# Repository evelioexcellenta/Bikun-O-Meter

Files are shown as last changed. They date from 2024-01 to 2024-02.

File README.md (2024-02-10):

# Bikun-O-Meter

## Overview
Our project aims to develop a web-based, battery-powered system for monitoring and analyzing crowd density at bus stops. Using ESP32CAM to capture images, the data is sent to a server to measure parameters such as headcount and stop area density. This system uses a TensorFlow lite framework and Real-time results are displayed on the website. 

## Concept
This system is divided into three parts: Electrical and Mechanical hardware, Image Recognition processing, and a Website. The microprocessor used is an ESP-32CAM, which connects to a WiFi Modem capable of transmitting captured pictures to Firebase Storage. The pictures are then downloaded by a Raspberry Pi 3B server and processed using an Image Recognition Algorithm from the TensorFlow Lite framework to identify the number of people and buses at the bus stop. The processed data is then uploaded to a website in real-time via the Firebase Realtime Database. For the power source, this system used a 5V battery module consisting of 2 18650 batteries connected in series and the voltage supply passes through a step-down buck converter.

The system provides a user-friendly web interface for accessing real-time data and includes a feature for storing historical data to observe crowd trends over time. With innovative technology and battery energy, this adaptable system can be installed at various bus stop locations without relying on external power sources.

## Battery Calculation
This system is aimed to operate without being connected to external power sources for at least a week. Therefore, we can estimate the required power. The system is set to turn on for 10 seconds and then go into DeepSleep mode for 50 seconds. So, it will be on for approximately 1.833 hours per day. If we want it to run for 7 days, it will be on for a total of 12.833 hours. Assuming an ESP32-CAM consumes 260mA of power, the battery capacity needed to power the system for 7 days is 3336.667 mAh. We use two Sony VCT6 batteries with a capacity of 3500mAh each, connected in series. We chose batteries with a capacity of 3500mAh to provide backup power so that the system could last for a week without shutting down immediately. Additionally, the batteries are connected in series to obtain a voltage of 7.4V - 8.4V, which will then be reduced to 5V using a buck converter module to be connected to the ESP32CAM.

## Result
Based on the assembly and testing stages, the results show that the tool is capable of sending information about the situation and crowd levels at the Faculty Bus Stop. The graph indicates that the crowd situation at the stop increases at certain times, namely during class schedules. Additionally, a decrease in the graph indicates that the  bus is present to transport passengers.

download 1

 ## Visit our website at: 
 https://bikun-o-meter.netlify.app/

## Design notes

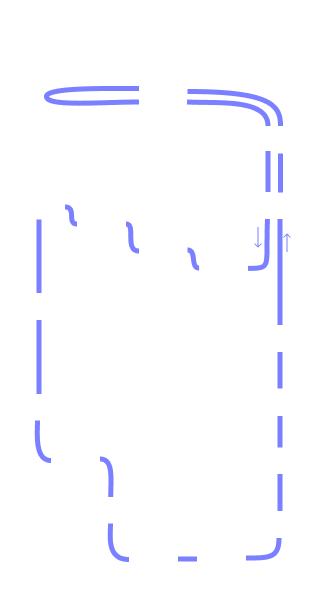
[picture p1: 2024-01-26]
Website/img/frame-7.png

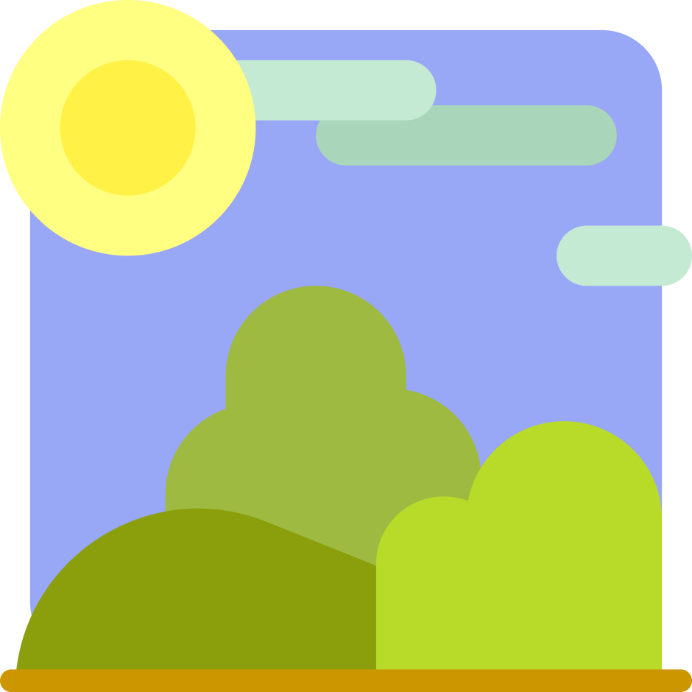
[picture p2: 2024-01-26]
Website/img/group-16.png

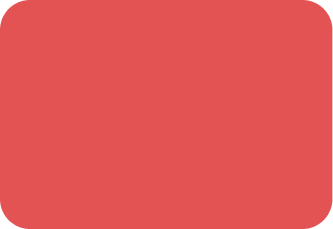
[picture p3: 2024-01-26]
Website/img/rectangle-16.png

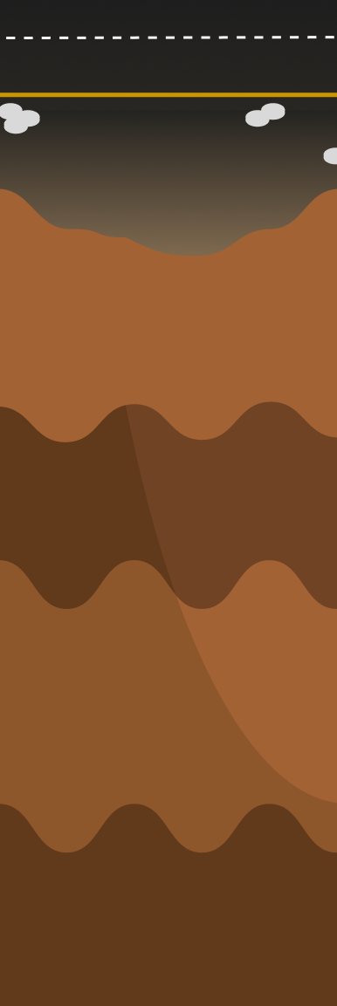
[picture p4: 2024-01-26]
Website/img/mask-group1.png

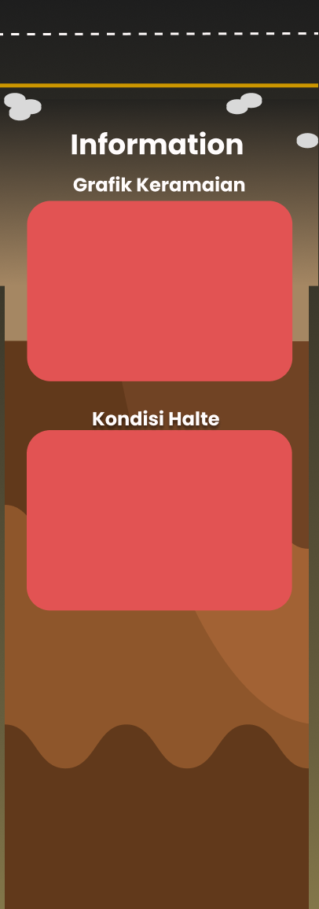
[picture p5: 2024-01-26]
Website/img/mask-group.png

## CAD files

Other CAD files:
Case/Casing Despro.iam
Case/Front.ipt
Case/fullback.ipt

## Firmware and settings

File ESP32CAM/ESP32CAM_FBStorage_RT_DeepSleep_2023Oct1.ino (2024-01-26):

#include "Arduino.h"
#include "WiFi.h"
#include "esp_camera.h"
#include "soc/soc.h"           // Disable brownout problems
#include "soc/rtc_cntl_reg.h"  // Disable brownout problems
#include "driver/rtc_io.h"
#include <LittleFS.h>
#include <FS.h>
#include <Firebase_ESP_Client.h>
//Provide the token generation process info.
#include <addons/TokenHelper.h>
#include "time.h"
//Provide the RTDB payload printing info and other helper functions.
#include "addons/RTDBHelper.h"
#define uS_TO_S_FACTOR 1000000ULL  /* Conversion factor for micro seconds to seconds */
#define TIME_TO_SLEEP  50        /* Time ESP32 will go to sleep (in seconds) */
int NightTime = 600; /*Time ESP will go to sleep 10 hours (10*60min)*/
//RTC_DATA_ATTR int bootCount = 0;
RTC_DATA_ATTR bool takeNewPhoto = true;

//Replace with your network credentials
const char* ssid = "wifi ssid";
const char* password = "wifi password";

const char* ntpServer = "pool.ntp.org";
const long  gmtOffset_sec = 7*3600;
const int   daylightOffset_sec = 0;

// Insert Firebase project API Key
#define API_KEY "input your API key"

// Insert Authorized Email and Corresponding Password
#define USER_EMAIL "input email"
#define USER_PASSWORD "input password"

// Insert Firebase storage bucket ID e.g bucket-name.appspot.com
#define STORAGE_BUCKET_ID "myhalte.appspot.com"
// Insert RTDB URLefine the RTDB URL
//#define DATABASE_URL ""

// Photo File Name to save in LittleFS
#define FILE_PHOTO_PATH "/photo.jpg"
#define BUCKET_PHOTO "/data/photo.jpg"

// OV2640 camera module pins (CAMERA_MODEL_AI_THINKER)
#define PWDN_GPIO_NUM     32
#define RESET_GPIO_NUM    -1
#define XCLK_GPIO_NUM      0
#define SIOD_GPIO_NUM     26
#define SIOC_GPIO_NUM     27
#define Y9_GPIO_NUM       35
#define Y8_GPIO_NUM       34
#define Y7_GPIO_NUM       39
#define Y6_GPIO_NUM       36
#define Y5_GPIO_NUM       21
#define Y4_GPIO_NUM       19
#define Y3_GPIO_NUM       18
#define Y2_GPIO_NUM        5
#define VSYNC_GPIO_NUM    25
#define HREF_GPIO_NUM     23
#define PCLK_GPIO_NUM     22

//boolean takeNewPhoto = true;

//Define Firebase Data objects
FirebaseData fbdo;
FirebaseAuth auth;
FirebaseConfig configF;
bool signupOK = false;

void fcsUploadCallback(FCS_UploadStatusInfo info);

bool taskCompleted = false;
int currentMinute;
int currentHour;

void printLocalTime()
{
  struct tm timeinfo;
 
  if(!getLocalTime(&timeinfo)){
    Serial.println("Failed to obtain time");
    return;
  }
  Serial.println(&timeinfo, "%A, %B %d %Y %H:%M:%S");
  currentMinute = timeinfo.tm_min;
  currentHour = timeinfo.tm_hour;
}


// Capture Photo and Save it to LittleFS
void capturePhotoSaveLittleFS( void ) {
  // Dispose first pictures because of bad quality
  camera_fb_t* fb = NULL;
  // Skip first 3 frames (increase/decrease number as needed).
  for (int i = 0; i < 4; i++) {
    fb = esp_camera_fb_get();
    esp_camera_fb_return(fb);
    fb = NULL;
  }
    
  // Take a new photo
  fb = NULL;  
  fb = esp_camera_fb_get();  
  if(!fb) {
    Serial.println("Camera capture failed");
    delay(1000);
    ESP.restart();
  }  

  // Photo file name
  Serial.printf("Picture file name: %s\n", FILE_PHOTO_PATH);
  File file = LittleFS.open(FILE_PHOTO_PATH, FILE_WRITE);

  // Insert the data in the photo file
  if (!file) {
    Serial.println("Failed to open file in writing mode");
  }
  else {
    file.write(fb->buf, fb->len); // payload (image), payload length
    Serial.print("The picture has been saved in ");
    Serial.print(FILE_PHOTO_PATH);
    Serial.print(" - Size: ");
    Serial.print(fb->len);
    Serial.println(" bytes");
  }
  // Close the file
  file.close();
  esp_camera_fb_return(fb);
}

void initWiFi(){
  WiFi.begin(ssid, password);
  while (WiFi.status() != WL_CONNECTED) {
    delay(1000);
    Serial.println("Connecting to WiFi...");
  }
}

void initLittleFS(){
  if (!LittleFS.begin(true)) {
    Serial.println("An Error has occurred while mounting LittleFS");
    ESP.restart();
  }
  else {
    delay(500);
    Serial.println("LittleFS mounted successfully");
  }
}

void initCamera(){
 // OV2640 camera module
  camera_config_t config;
  config.ledc_channel = LEDC_CHANNEL_0;
  config.ledc_timer = LEDC_TIMER_0;
  config.pin_d0 = Y2_GPIO_NUM;
  config.pin_d1 = Y3_GPIO_NUM;
  config.pin_d2 = Y4_GPIO_NUM;
  config.pin_d3 = Y5_GPIO_NUM;
  config.pin_d4 = Y6_GPIO_NUM;
  config.pin_d5 = Y7_GPIO_NUM;
  config.pin_d6 = Y8_GPIO_NUM;
  config.pin_d7 = Y9_GPIO_NUM;
  config.pin_xclk = XCLK_GPIO_NUM;
  config.pin_pclk = PCLK_GPIO_NUM;
  config.pin_vsync = VSYNC_GPIO_NUM;
  config.pin_href = HREF_GPIO_NUM;
  config.pin_sscb_sda = SIOD_GPIO_NUM;
  config.pin_sscb_scl = SIOC_GPIO_NUM;
  config.pin_pwdn = PWDN_GPIO_NUM;
  config.pin_reset = RESET_GPIO_NUM;
  config.xclk_freq_hz = 20000000;
  config.pixel_format = PIXFORMAT_JPEG;
  config.grab_mode = CAMERA_GRAB_LATEST;

  if (psramFound()) {
    config.frame_size = FRAMESIZE_UXGA;
    config.jpeg_quality = 10;
    config.fb_count = 1;
  } else {
    config.frame_size = FRAMESIZE_SVGA;
    config.jpeg_quality = 12;
    config.fb_count = 1;
  }
  // Camera init
  esp_err_t err = esp_camera_init(&config);
  if (err != ESP_OK) {
    Serial.printf("Camera init failed with error 0x%x", err);
    ESP.restart();
  } 
}

void setup() {time_t now;
  // Serial port for debugging purposes
  Serial.begin(115200);

  initWiFi();
  initLittleFS();
  // Turn-off the 'brownout detector'
  WRITE_PERI_REG(RTC_CNTL_BROWN_OUT_REG, 0);
  initCamera();

  //Firebase
  // Assign the api key
  configF.api_key = API_KEY;
  //Assign the user sign in credentials
  auth.user.email = USER_EMAIL;
  auth.user.password = USER_PASSWORD;
  //Assign the callback function for the long running token generation task
  configF.token_status_callback = tokenStatusCallback; //see addons/TokenHelper.h

  Firebase.begin(&configF, &auth);
  Firebase.reconnectWiFi(true);

  configTime(gmtOffset_sec, daylightOffset_sec, ntpServer);
  printLocalTime();

  TakePhoto();

  if ((currentHour >= 21) || (currentHour < 6)){
    esp_sleep_enable_timer_wakeup(NightTime* 60 * uS_TO_S_FACTOR);
    Serial.println("Good Night and see you tomorrow");
  }
  else {
    esp_sleep_enable_timer_wakeup(TIME_TO_SLEEP * uS_TO_S_FACTOR);
    Serial.println("Setup ESP32 to sleep for every " + String(TIME_TO_SLEEP) +
    " Seconds");
  }
  Serial.println("Going to sleep now");
  Serial.flush(); 
  esp_deep_sleep_start();
  Serial.println("This will never be printed");
}

void TakePhoto() {
  Serial.print("currentHour = ");
  Serial.println(currentHour);
  Serial.print("currentMinute = ");
  Serial.println (currentMinute);
  Serial.print ("takeNewPhoto = ");
  Serial.println (takeNewPhoto);
  
  if ((takeNewPhoto)&&(currentMinute%2==1)) {
    takeNewPhoto = false; 
    capturePhotoSaveLittleFS();
    delay(1);
    if (Firebase.ready() && !taskCompleted){
      Serial.print("Uploading picture... ");

      //MIME type should be valid to avoid the download problem.
      //The file systems for flash and SD/SDMMC can be changed in FirebaseFS.h.
      if (Firebase.Storage.upload(&fbdo, STORAGE_BUCKET_ID /* Firebase Storage bucket id */, FILE_PHOTO_PATH /* path to local file */, mem_storage_type_flash /* memory storage type, mem_storage_type_flash and mem_storage_type_sd */, BUCKET_PHOTO /* path of remote file stored in the bucket */, "image/jpeg" /* mime type */,fcsUploadCallback)){
        Serial.printf("\nDownload URL: %s\n", fbdo.downloadURL().c_str());
      }
      else{
        Serial.println(fbdo.errorReason());
      }
    }
  }
  else if (currentMinute%2==0) {
    takeNewPhoto = true;
    Serial.println("Genap..., tidak ambil photo dulu");
  }
  printLocalTime();  
  delay(3000);
}

// The Firebase Storage upload callback function
void fcsUploadCallback(FCS_UploadStatusInfo info){
    if (info.status == firebase_fcs_upload_status_init){
        Serial.printf("Uploading file %s (%d) to %s\n", info.localFileName.c_str(), info.fileSize, info.remoteFileName.c_str());
    }
    else if (info.status == firebase_fcs_upload_status_upload)
    {
        Serial.printf("Uploaded %d%s, Elapsed time %d ms\n", (int)info.progress, "%", info.elapsedTime);
    }
    else if (info.status == firebase_fcs_upload_status_complete)
    {
        Serial.println("Upload completed\n");
        FileMetaInfo meta = fbdo.metaData();
        Serial.printf("Name: %s\n", meta.name.c_str());
        Serial.printf("Bucket: %s\n", meta.bucket.c_str());
        Serial.printf("contentType: %s\n", meta.contentType.c_str());
        Serial.printf("Size: %d\n", meta.size);
        Serial.printf("Generation: %lu\n", meta.generation);
        Serial.printf("Metageneration: %lu\n", meta.metageneration);
        Serial.printf("ETag: %s\n", meta.etag.c_str());
        Serial.printf("CRC32: %s\n", meta.crc32.c_str());
        Serial.printf("Tokens: %s\n", meta.downloadTokens.c_str());
        Serial.printf("Download URL: %s\n\n", fbdo.downloadURL().c_str());
    }
    else if (info.status == firebase_fcs_upload_status_error){
        Serial.printf("Upload failed, %s\n", info.errorMsg.c_str());
    }
}

void loop(){
  
}
